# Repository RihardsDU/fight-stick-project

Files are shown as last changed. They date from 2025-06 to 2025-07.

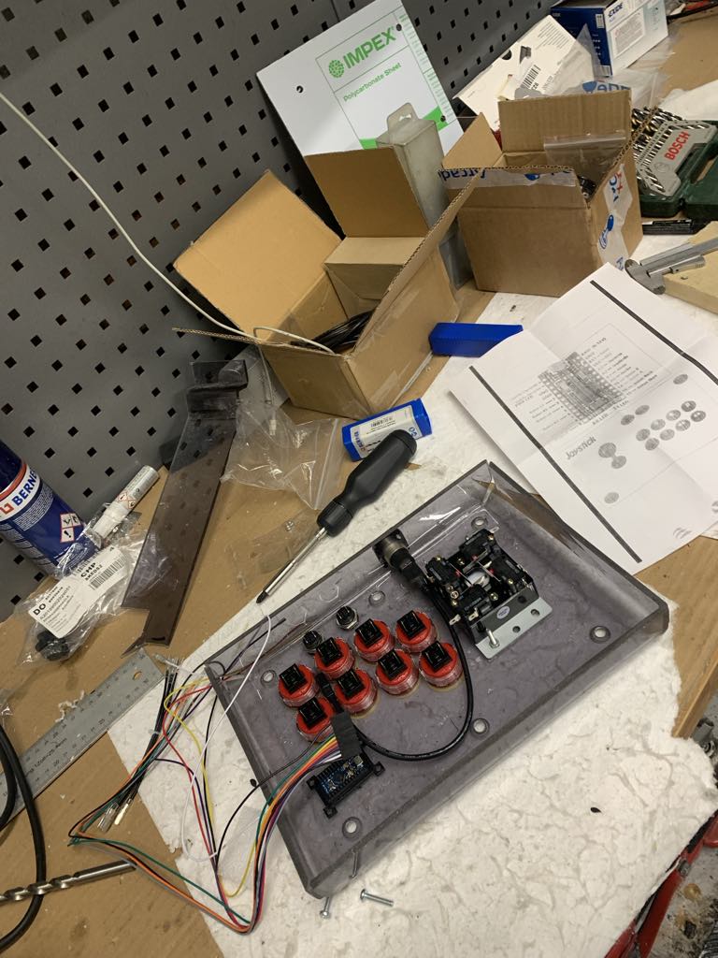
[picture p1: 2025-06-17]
pictures/wip-wiring.jpg

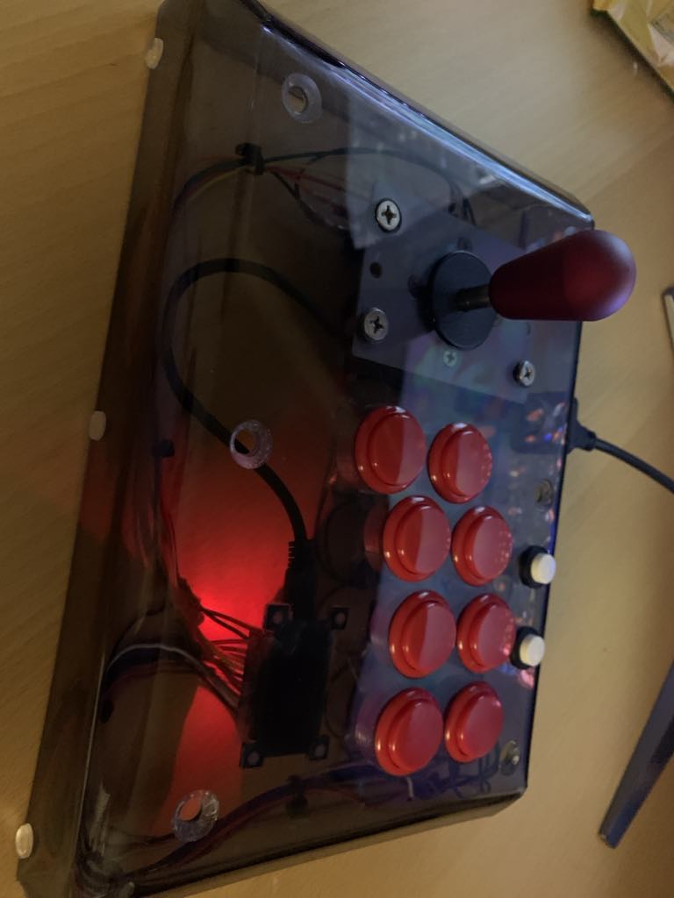
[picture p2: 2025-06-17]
pictures/finished-missing-bottom-plate.jpg

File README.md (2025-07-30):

# Custom Fightstick Project

This repository contains all documentation and resources related to my custom-built arcade fightstick.

## Project Overview

This project involved designing and building a custom arcade fightstick from the ground up, including:

- Designing and building the case
- Selecting and installing joystick and buttons
- Wiring all components to a custom controller encoder
- Adding USB connectivity
- Ensuring durable construction and good ergonomics

## Components Used

| Component | Description / Link |
|---|---|
| **Joystick** | [Crown CWL-303MJ-DX "New Crazy Dongpal" (Clear Red)](https://paradisearcadeshop.com/collections/joysticks/products/crown-cwl-303mj-dx-new-crazy-dongpal-lever-clear-red) |
| **Buttons** | [Crown Samducksa SDB-202 Cherry 30mm Screw-In (Red)](https://paradisearcadeshop.com/products/crown-samducksa-sdb-202-cherry-30-mm-screw-in-button-red) |
| **Extra Buttons** | [Cabinet Flipper Button 1-1/8" (White)](https://paradisearcadeshop.com/products/cabinet-flipper-button-1-18-white) |
| **Controller Encoder** | [KTRL Arcade by Daemonbite](https://www.daemonbite.com/product/ktrl-arcade/) |
| **Button Layout Template** | [ArcadeControls.com Downloads (Misc)](https://arcadecontrols.com/arcade_downloads.shtml#Miscellaneous) |
| **Spacer Bolts** | [Biltema M8 x 35mm Coupling Nuts (2 pcs)](https://www.biltema.no/bygg/festeelementer/muttere/skjotemutter-m8-x-35-mm-elforsinket-2-stk-2000061118) |
| **Bolts** | M8 Flat Head Bolts (Generic) |
| **Nylon Washers** | [Biltema Nylon Washers Assortment (200 pcs)](https://www.biltema.no/bil---mc/verkstedsutstyr/festeelementer/brikker/fiber--og-nylonskiver-200-stk-2000033227) |
| **USB Cable** | [3m USB 2.0 Male to Male (Eletra)](https://www.power.no/mobil-og-foto/ladere-og-kabler/usb-ladekabel/eletra-usb-20-am-3m-kabel-svart/p-1251714/store) |
| **USB Port** | [Neutrik NAUSB3 USB passthrough panel mount](https://www.neutrik.com/en/product/nausb3) |
| **Anti-Slip Rubber** | [Clas Ohlson Anti-Slip Mat (70x38 cm)](https://www.clasohlson.com/no/Antisklimatte-70-x-38-cm/p/34-2786-1) |

## Design & Build Notes

- Low latency encoder source code: https://github.com/MickGyver/DaemonBite-Arcade-Encoder
- The case was designed with spacing in mind to accommodate the joystick lever and all wiring.
- Button layout was based on arcade standards using the template from ArcadeControls.
- Screws and spacers were used to provide a sturdy base and good mounting for the top panel.
- Nylon washers were used to reduce vibration and protect surfaces.
- Anti-slip rubber matting was added to the base for stability during use.

## Research & References

- **Joystick and Button Types:** Crown/Samducksa buttons provide excellent feel and feedback. The CWL-303MJ lever offers a loose Korean-style movement with a rubber grommet instead of a spring.
- **Encoder:** The Daemonbite KTRL Arcade is a low-latency, open-source USB controller encoder compatible with PC and many consoles. It provides excellent responsiveness.
- **USB Integration:** The Neutrik NAUSB3 panel mount provides a professional-grade USB passthrough port, mounted on the case for clean external connection.
- **Construction Tips:** Spacer bolts allow for layered construction of panels, and nylon washers help reduce wear on parts.
- **Case material:** I chose polycarbonate over plexiglass (acrylic) because it's significantly more impact-resistant and less prone to cracking. Polycarbonate is also easier to drill without chipping, making it a better choice for precise button and joystick mounting.

---

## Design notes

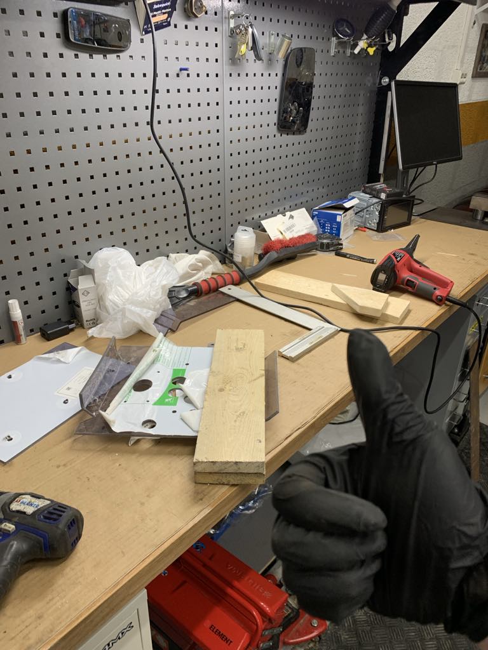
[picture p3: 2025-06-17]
pictures/wip-bending-top-enclosure.jpg

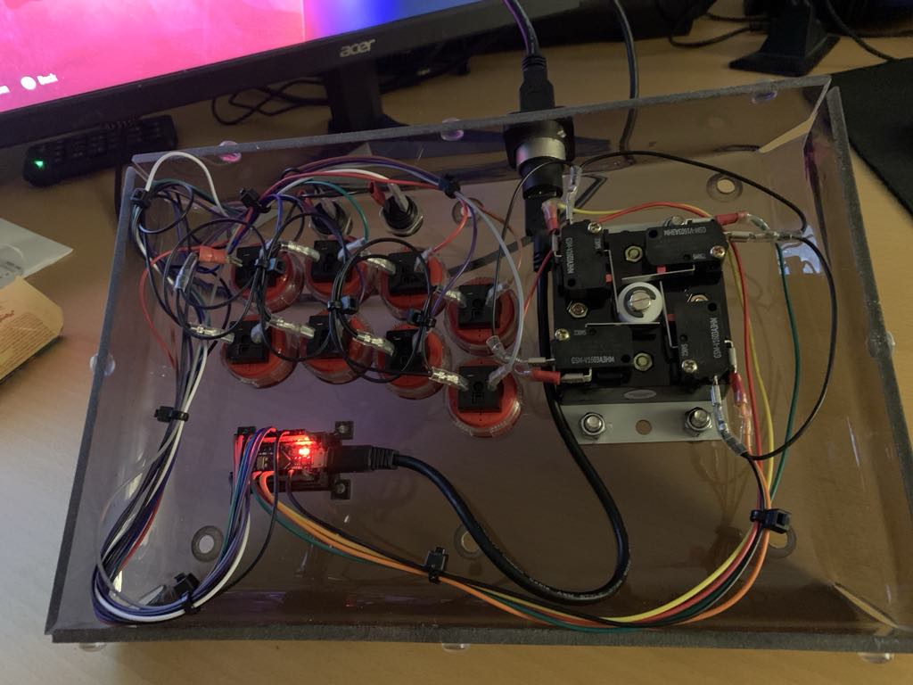
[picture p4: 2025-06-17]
pictures/finished-wireing.jpg

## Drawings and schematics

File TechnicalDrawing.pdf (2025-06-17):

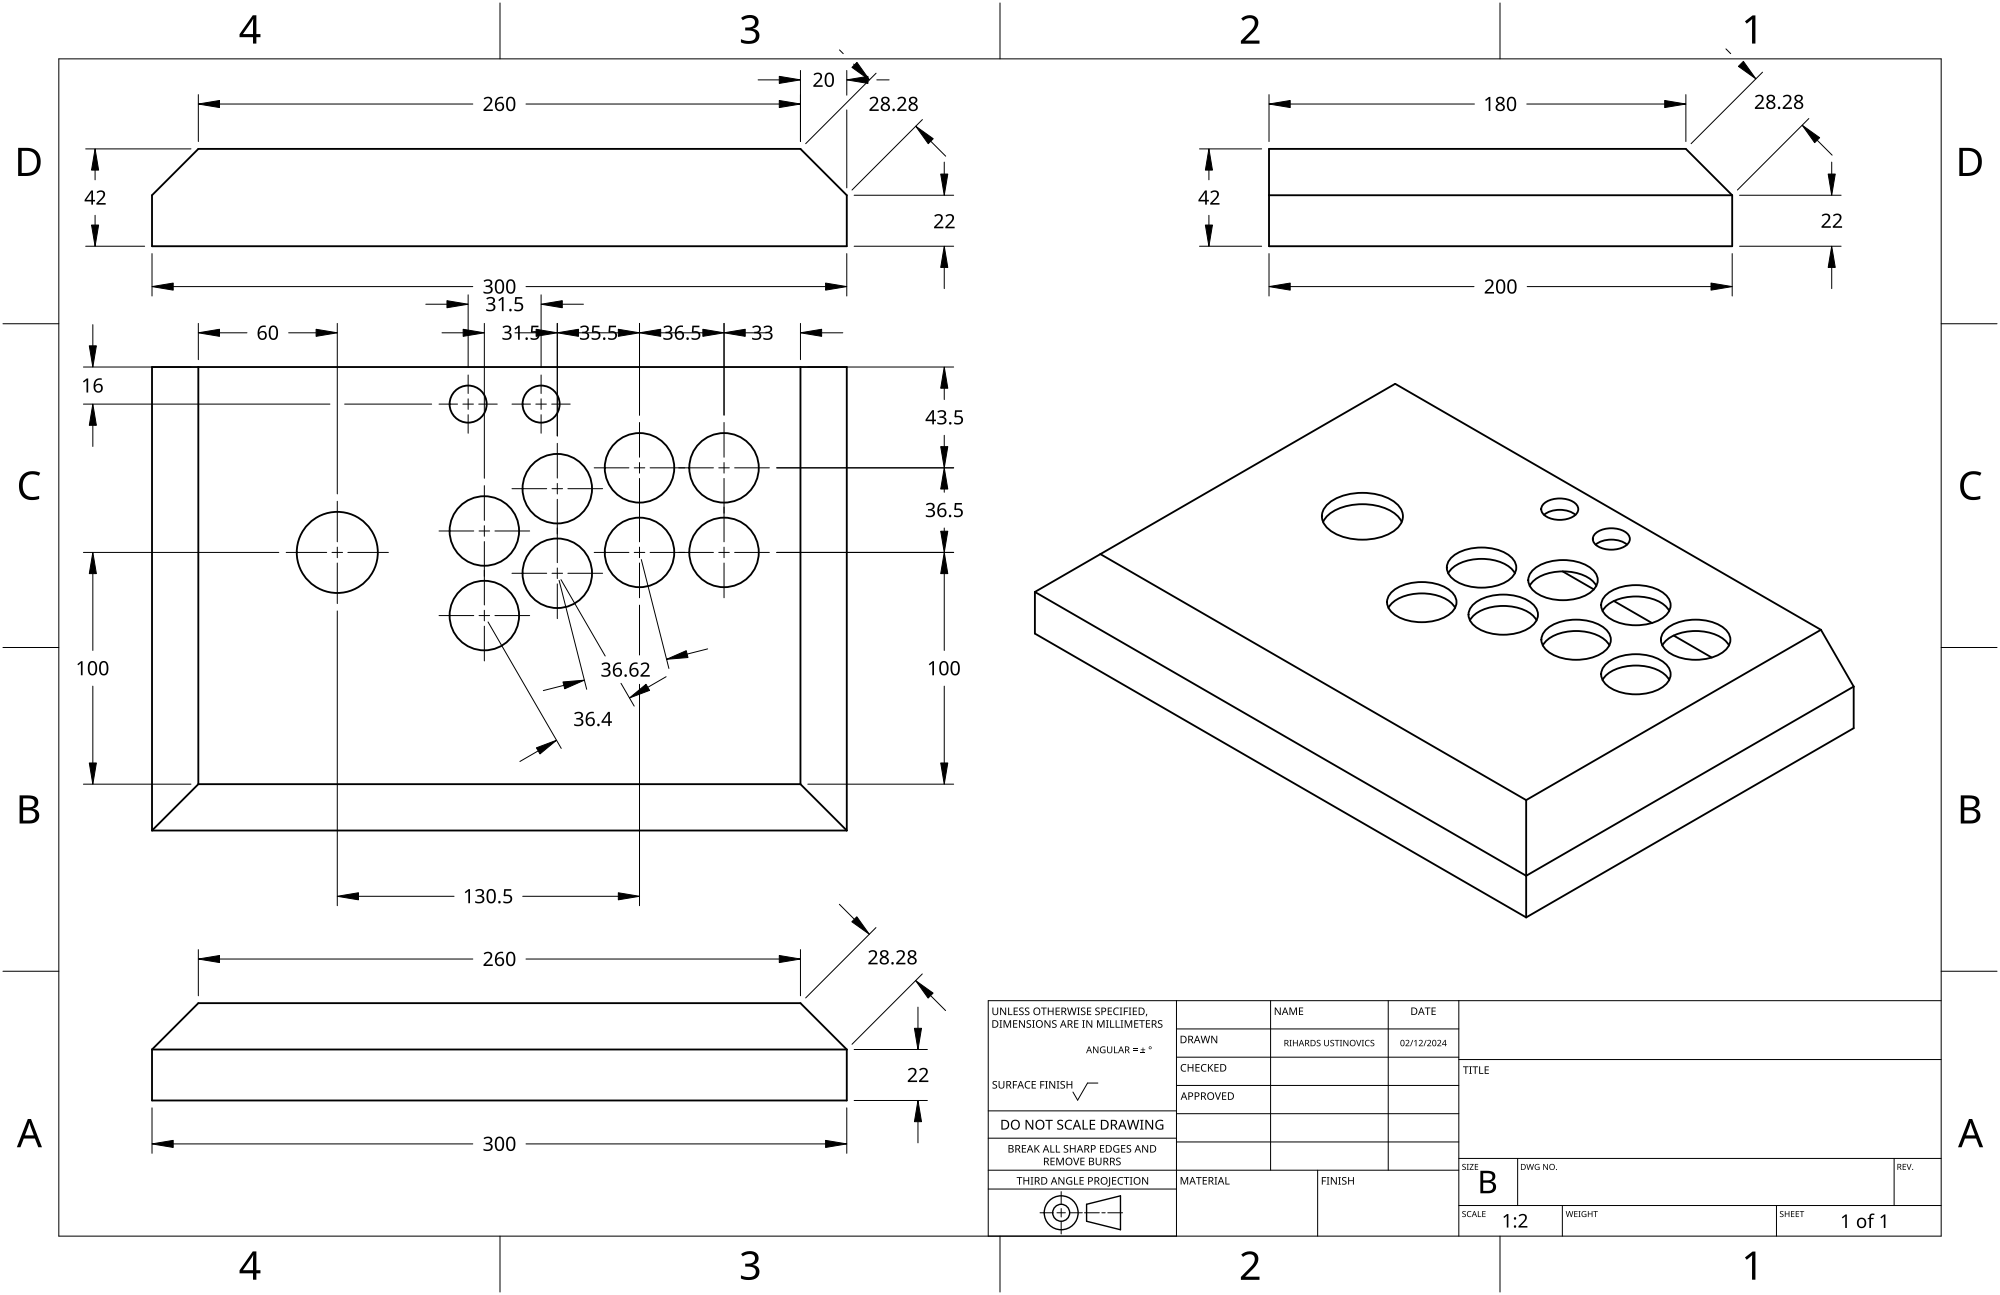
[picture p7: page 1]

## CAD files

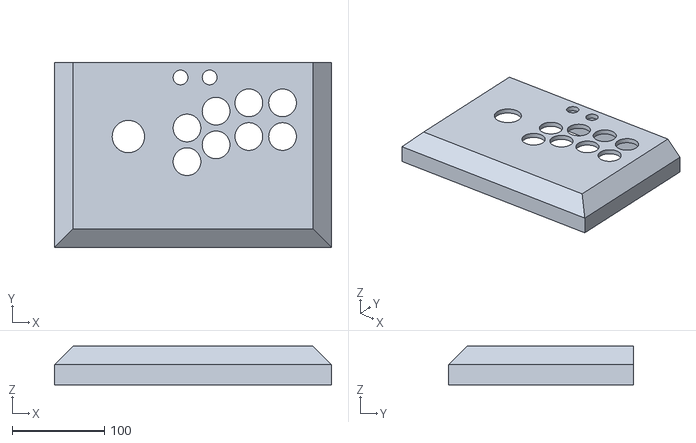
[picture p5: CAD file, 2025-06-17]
Top3dView.stl
300.0 x 200.0 x 42.0

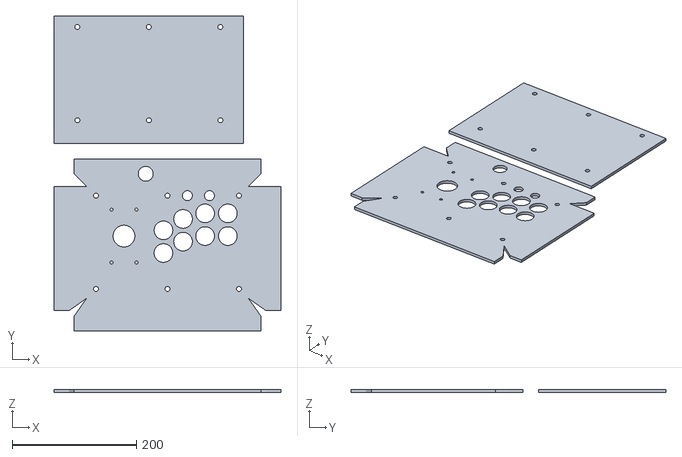
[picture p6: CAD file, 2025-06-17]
PartsFlat.stl
365.0 x 506.2 x 5.00

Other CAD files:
toolPath_top.dwg
toolPath_bottom.dwg
